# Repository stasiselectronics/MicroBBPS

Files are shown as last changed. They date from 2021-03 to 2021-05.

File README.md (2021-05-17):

# MicroBBPS
<h3>Breadboard Power Supply</h3>
<BR CLEAR=”left” />


A small, Micro USB connected power supply designed to fit onto the power rails of a solderless breadboard.

For each side, you can select between 3.3 & 5.0 Volt linear regulators, or the input voltage at the screw terminal. 

The integrated version adds 26 breadboard rows and 2 continuous power rails. So you can turn those prototypes into something more permanent with an easy microUSB power connector.

<h4><a href="https://github.com/stasiselectronics/MicroBBPS/tree/variant-integrated">Check out the integrated version's repository branch</a></h4>

## Documentation

If you would like to read more about how the design works and see some of the technical information, be sure to check out the documentation site that accompanies this project.

<h3><a href="https://stasiselectronics.github.io/MicroBBPS/">Read the Docs</a></h3>

This site is hosted on Github Pages, a great way to deploy your own static website using jekyll. It uses the wonderful theme [Minimal Mistakes](https://mmistakes.github.io/minimal-mistakes/about/) by Michael Rose.

[Learn more about github pages.](https://pages.github.com/)

## Development
This open source hardware project is developed using KiCAD and inkscape. It exists as a schematic and pcb design, with supporting files to create the necesarry output files for Printed Circuit Board fabrication.

[Learn more about KiCAD](https://kicad.org/about/kicad/)

## Status

Assemblies and Parts Kits are still available to purchase on Tindie, however current stock is starting to run low.

[Order Yours Today!](https://www.tindie.com/products/stasis/micro-breadboard-power-supply/)

The PCBA is currently at Revision A02. The tag for this release contians all the design files as they were when fabrication files were generated.

## Updates
If you would like to keep up to date with this project, be sure to check out my instagram

<h3><a href="https://www.instagram.com/stasis.electronics/">stasis.electronics</a></h3>

### A02 Fabrication

After incorporating the design changes from the first revision, the second revision came out great! 

There are still a few details to try and adjust for any future fabrication.
- Silkscreen adjustments for better image fidelity
- Still have some mechanical rocking on the solderless version when inserted into a breadboard

Some of the major changes between on A02 from A01 are
- Smaller board shape
- Changed LEDs to 1206 for better part availability and easier hand soldering
- Larger silkscreen features
- Integrated version

### A01 Fabrication
Here are some photos of the first board revision
<p align="center">
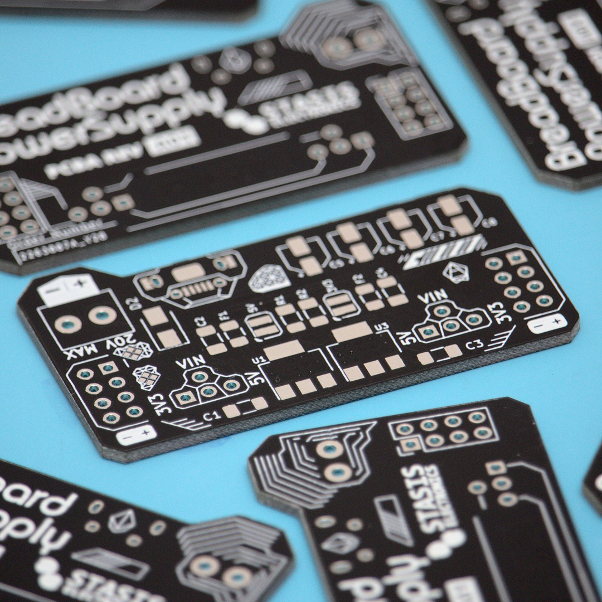
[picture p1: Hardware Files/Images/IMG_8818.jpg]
  
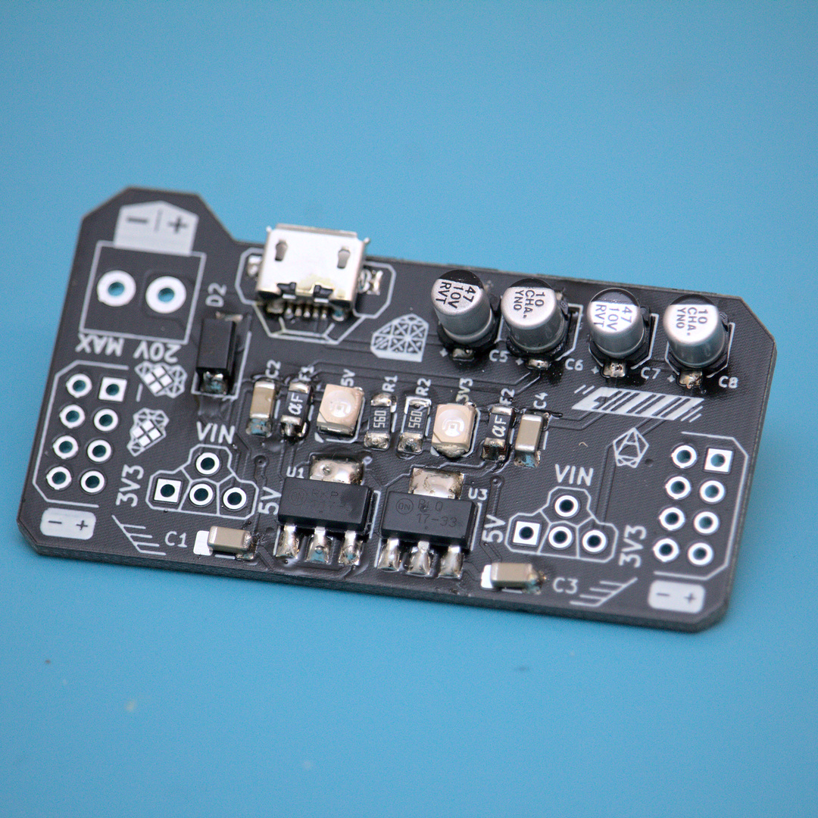
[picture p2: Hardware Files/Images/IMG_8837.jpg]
  
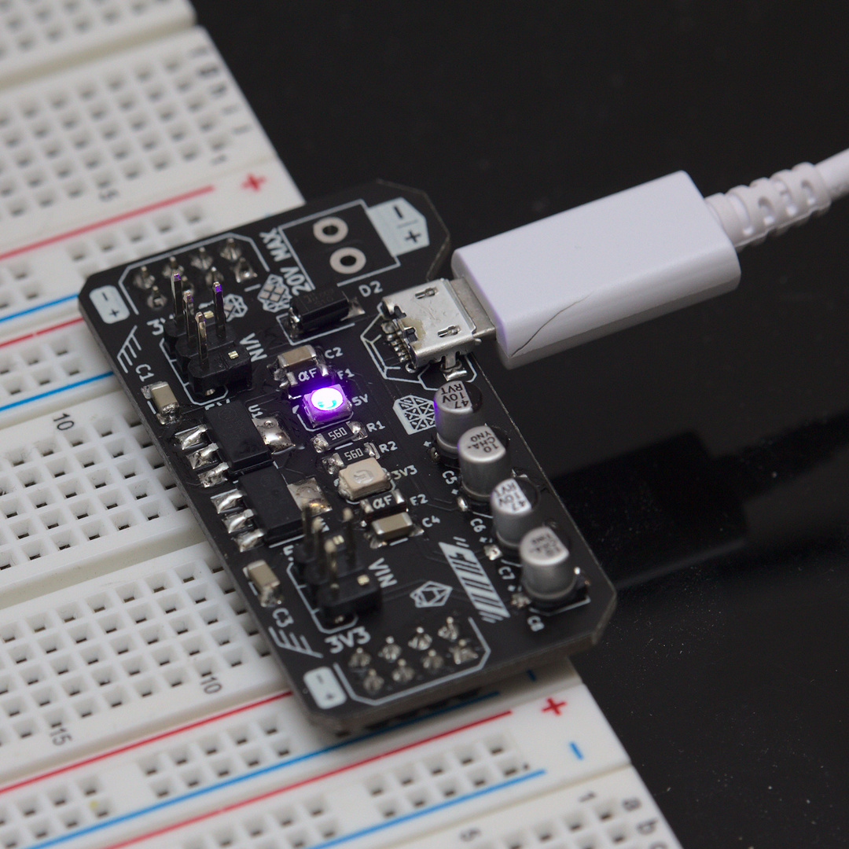
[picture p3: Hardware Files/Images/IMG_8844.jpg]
  
</p>

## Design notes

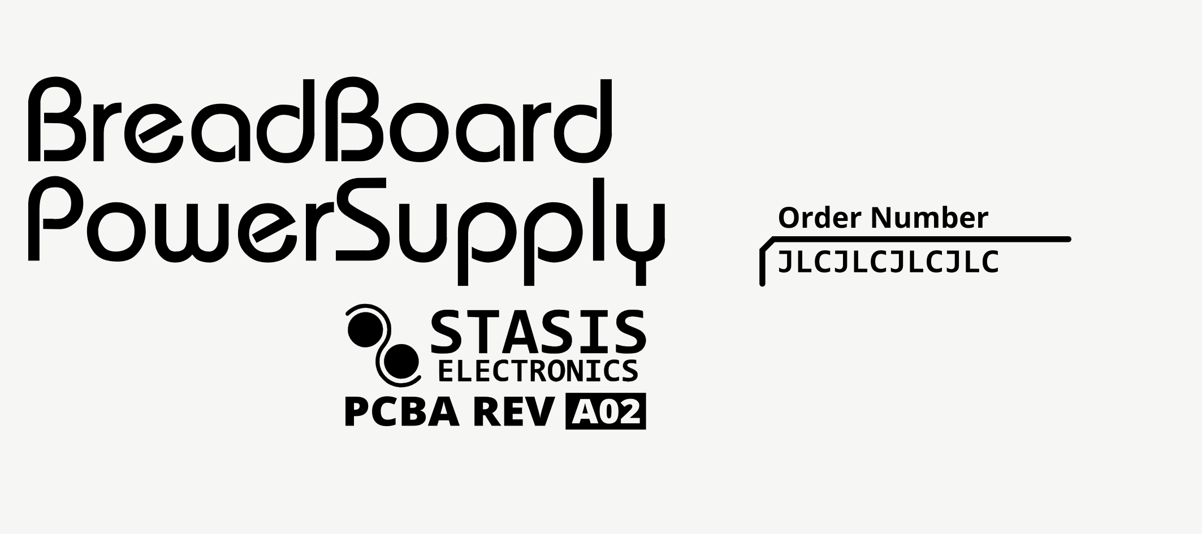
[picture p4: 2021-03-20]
Hardware Files/Input Files/artwork-bottom.png

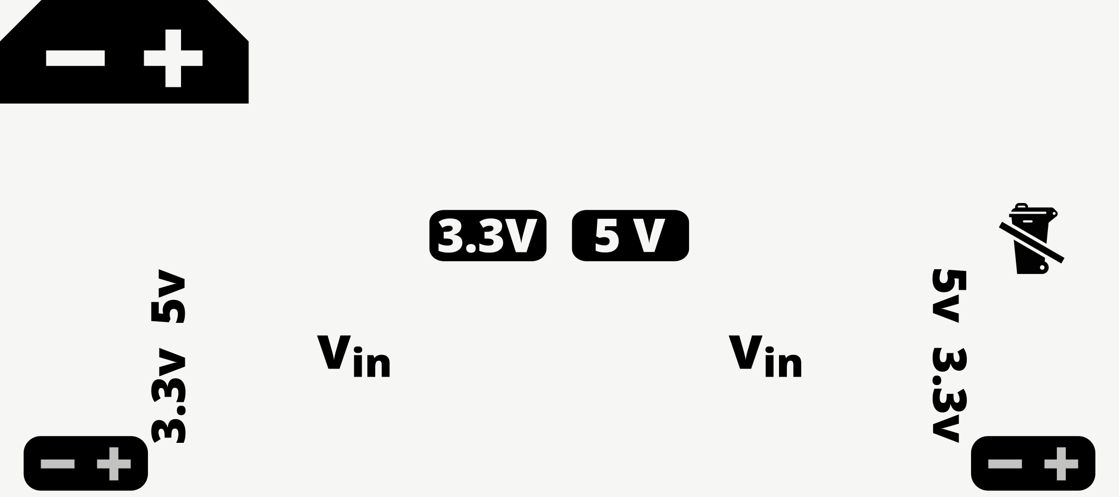
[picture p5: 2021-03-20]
Hardware Files/Input Files/artwork-top.png

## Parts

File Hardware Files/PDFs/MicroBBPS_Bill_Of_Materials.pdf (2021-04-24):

# Micro Breadboard Power Supply

Item Qty | Designator | Value | Part 1 MF | Part 1 MPN
1 | 2 | C5 C7 | 10µF 16V | Panasonic | EEEHA1C100R
2 | 4 | C1 C2 C3 C4 | 220nF 50V | YAGEO | CC1206KKX7R9BB224
3 | 2 | C6 C8 | 47µF 10V | ROQANG | RVT1A470M0405
4 | 1 | D2 | D | Diodes Incorporated | S1G-13-F
5 | 2 | D1 D3 | LED | EKINGLUX | E6C1206VGAC1UDA
6 | 4 | J3 J4 J8 J9 | 2x3 Header 2.54mm | XFCN | PZ254V-12-6P
7 | 1 | J5 | 1x2 Screw Terminal | Ningbo Kangnex Elec | WJ124-3.81-2P
8 | 1 | J2 | Micro USB Connector | Korean Hroparts Elec | U-F-M5DD-Y-L
9 | 2 | R1 R2 | 10k 0.25W | YAGEO | RC1206JR-0710KL
10 | 1 | U1 | 5.0V 1A linear Reg | ON Semiconductor | NCP1117ST50T3G
11 | 1 | U3 | 3.3V 1A Linear Reg | ON Semiconductor | NCP1117ST33T3G

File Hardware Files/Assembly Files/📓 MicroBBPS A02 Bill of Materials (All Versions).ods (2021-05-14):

Micro Breadboard Power Supply
Solderless
Item | Qty | Designator | Value | Part 1 MF | Part 1 MPN
1 | 2 | C5 C7 | 10µF 16V | Panasonic | EEEHA1C100R | ☐
2 | 4 | C1 C2 C3 C4 | 220nF 50V | YAGEO | CC1206KKX7R9BB224 | ☐
3 | 2 | C6 C8 | 47µF 10V | ROQANG | RVT1A470M0405 | ☐
4 | 1 | D2 | Gen Purp 400V 1A | Diodes Incorporated | S1G-13-F | ☐
5 | 2 | D1 D3 | Green LED | EKINGLUX | E6C1206VGAC1UDA | ☐
6 | 2 | J3 J4 | 2x3 Header 2.54mm | XFCN | PZ254V-12-6P | ☐
7 | 2 | J8 J9 | Modified Header | XFCN | PZ254V-12-6P | ☐
8 | 1 | J5 | 1x2 Screw Terminal | Ningbo Kangnex Elec | WJ124-3.81-2P | ☐
9 | 1 | J2 | Micro USB Connector | Korean Hroparts Elec | U-F-M5DD-Y-L | ☐
10 | 2 | R1 R2 | 10k 0.25W | YAGEO | RC1206JR-0710KL | ☐
11 | 1 | U1 | 5.0V 1A linear Reg | ON Semiconductor | NCP1117ST50T3G | ☐
12 | 1 | U3 | 3.3V 1A Linear Reg | ON Semiconductor | NCP1117ST33T3G | ☐
Micro Breadboard Power Supply
Integrated
Item | Qty | Designator | Value | Part 1 MF | Part 1 MPN
1 | 2 | C5 C7 | 10µF 16V | Panasonic | EEEHA1C100R | ☐
2 | 4 | C1 C2 C3 C4 | 220nF 50V | YAGEO | CC1206KKX7R9BB224 | ☐
3 | 2 | C6 C8 | 47µF 10V | ROQANG | RVT1A470M0405 | ☐
4 | 1 | D2 | Gen Purp 400V 1A | Diodes Incorporated | S1G-13-F | ☐
5 | 2 | D1 D3 | Green LED | EKINGLUX | E6C1206VGAC1UDA | ☐
6 | 2 | J8 J9 | Modified Header | XFCN | PZ254V-12-6P | ☐
7 | 1 | J5 | 1x2 Screw Terminal | Ningbo Kangnex Elec | WJ124-3.81-2P | ☐
8 | 1 | J2 | Micro USB Connector | Korean Hroparts Elec | U-F-M5DD-Y-L | ☐
9 | 2 | R1 R2 | 10k 0.25W | YAGEO | RC1206JR-0710KL | ☐
10 | 1 | U1 | 5.0V 1A linear Reg | ON Semiconductor | NCP1117ST50T3G | ☐
11 | 1 | U3 | 3.3V 1A Linear Reg | ON Semiconductor | NCP1117ST33T3G | ☐

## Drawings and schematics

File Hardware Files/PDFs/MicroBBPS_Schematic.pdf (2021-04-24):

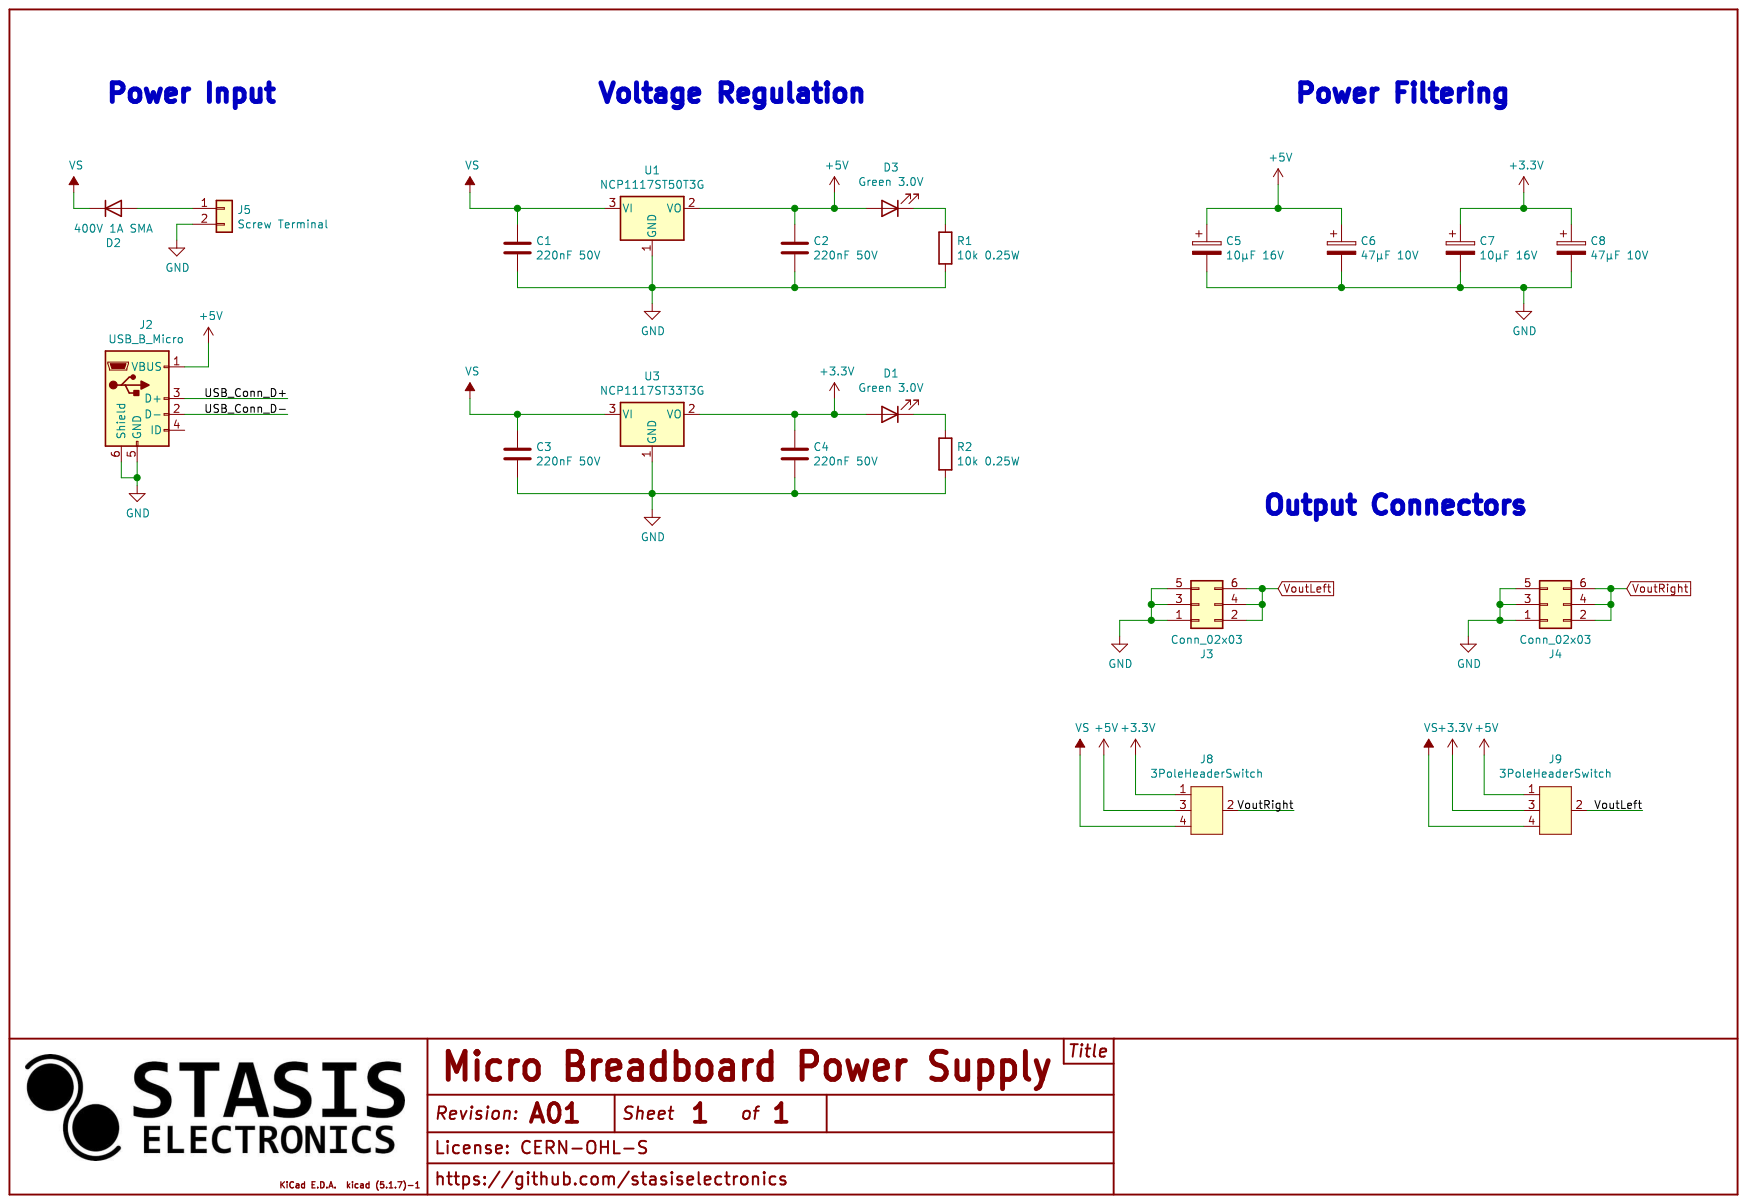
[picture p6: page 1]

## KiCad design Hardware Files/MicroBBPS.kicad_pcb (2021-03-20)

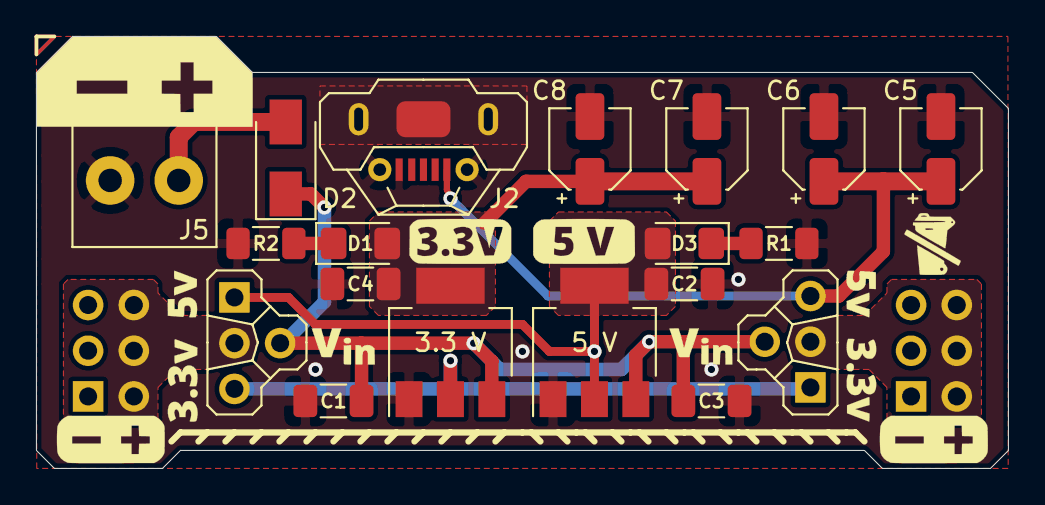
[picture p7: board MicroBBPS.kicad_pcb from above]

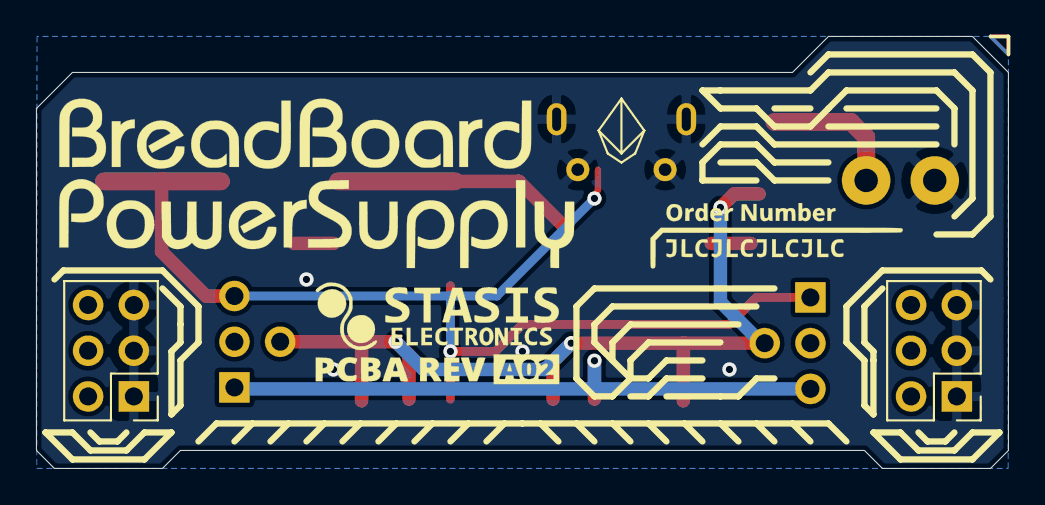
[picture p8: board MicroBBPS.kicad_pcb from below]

Board: 2 copper layers, 54.0 x 24.0 mm, 21 parts (2 on the bottom side), 9 nets.

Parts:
C1, C2, C3, C4: 220nF 50V; C_1206_3216Metric_Pad1.33x1.80mm_HandSolder
C5, C7: 10µF 16V; CP_Elec_4x5.4
C6, C8: 47µF 10V; CP_Elec_4x5.4
D1, D3: LED; D_1206_3216Metric_Pad1.42x1.75mm_HandSolder
D2: D; D_SMA
J2: USB_B_Micro; U-F-M5DD-Y-L
J3, J4: Conn_02x03; PinHeader_2x03_P2.54mm_Vertical
J5: Conn_01x02; WJ124-3.81-2P
J8, J9: 3PoleHeaderSwitch
R1: 56R 0.25W; R_1206_3216Metric_Pad1.30x1.75mm_HandSolder
R2: 0R; R_1206_3216Metric_Pad1.30x1.75mm_HandSolder
U1: NCP1117ST50T3G; SOT-223-3_TabPin2
U3: NCP1117ST33T3G; SOT-223-3_TabPin2

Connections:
+3V3: C4.1, C7.1, C8.1, D1.2, J8.1, J9.3, U3.2
+5V: C2.1, C5.1, C6.1, D3.2, J2.1, J8.3, J9.1, U1.2
/VoutLeft: J3.2, J3.4, J3.6, J9.2
/VoutRight: J4.2, J4.4, J4.6, J8.2
GND: C1.2, C2.2, C3.2, C4.2, C5.2, C6.2, C7.2, C8.2, J2.5, J2.6, J3.1, J3.3, J3.5, J4.1, J4.3, J4.5, J5.2, R1.2, R2.2, U1.1, U3.1
unnamed: D1.1, R2.1
unnamed: D2.2, J5.1
unnamed: D3.1, R1.1
VS: C1.1, C3.1, D2.1, J8.4, J9.4, U1.3, U3.3

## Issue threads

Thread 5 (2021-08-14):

Pin spacing

ilium007, 2021-08-14:
What is the exact distance between the outer pins? Thanks.

ChandlerMcCowan, 2021-08-14:
Hi!

The outer pins that interface with a breadboard are 1.9 inches apart.

This is the same on the integrated version as well.

Hope this helps and feel free to ask any follow up questions!

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

ilium007, 2021-08-14:
Thanks!

ilium007, 2021-08-14:
Sorry, one more question. How do you do those awesome reverse labels (3.3v / 5v)

ChandlerMcCowan, 2021-08-14:
No worries,

I use Inkscape to draw some of the artwork and then import it into KICAD as a footprint that just has silkscreen on it.

That makes it possible to use extra fonts, and draw more elaborate shapes.

Here's a video tutorial for [cutting text out of shapes in inkscape](https://www.youtube.com/watch?v=Men1K2oMq8g)

Keysight recently did a video about PCB artwork, I haven't watched it yet but [here it is](https://www.youtube.com/watch?v=0lomLQOFW8U)

ilium007, 2021-08-14:
So good! Thanks again.

ilium007, 2021-08-14:
I knew I had 'liked' something similar on Twitter a while back and just went back through my history and found it!

https://github.com/gregdavill/KiBuzzard

![Uploading C5B3B605-FD92-488B-B635-5E0F1B7A76FB.jpeg…]()

ilium007, 2021-08-14:
Works beautifully for simple text!

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

ChandlerMcCowan, 2021-08-14:
Nice! Looks good!

Closed 2021-08-14.

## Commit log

2020-11-11 Moved files into Hardware Files folder
    [MicroBBPS.kicad_pcb, MicroBBPS.sch]
2020-11-11 Add new page layout
    [MicroBBPS.sch]
2020-11-11 update page layout
    [MicroBBPS.kicad_pcb]
2021-01-07 Change board size to full breadboard length Move around components add 5v regulator add input terminal
    [MicroBBPS.kicad_pcb, MicroBBPS.sch]
2021-01-07 update layout add artwork update footprints
    [MicroBBPS.kicad_pcb, MicroBBPS.sch]
2021-01-07 Add footprint library add logos modify board shape add pours route some traces
    [MicroBBPS.kicad_pcb]
2021-01-08 Add new parts
    [MicroBBPS.sch]
2021-01-08 add 3D model
    [MicroBBPS.kicad_pcb]
2021-01-08 Change board shape Add more art finalize components finalize placement finalize routing
    [MicroBBPS.kicad_pcb, MicroBBPS.sch]
2021-01-09 Add part details
    [MicroBBPS.kicad_pcb, MicroBBPS.sch]
2021-01-09 Finalize components Finalize placement Finalize art Finalize BoM
    [MicroBBPS.kicad_pcb, MicroBBPS.sch, MicroBBPS_bom_A01.csv]
2021-01-09 Add Gerbers & NC Drill Files
    [MicroBBPS-B_Cu.gbr, MicroBBPS-B_Mask.gbr, MicroBBPS-B_SilkS.gbr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]
2021-01-09 change layer views
    [MicroBBPS.kicad_pcb]
2021-01-13 Finalize A01 Design
    [MicroBBPS-B_Cu.gbr, MicroBBPS-B_Mask.gbr, MicroBBPS-B_SilkS.gbr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]
2021-01-28 Add schematic PDF
2021-01-30 Update MPN and ordering code for Screw Terminal
    [MicroBBPS.sch]
2021-02-16 Add breadboard sections
    [MicroBBPS.kicad_pcb, MicroBBPS.sch]
2021-03-13 Clear Board Layout to redo it
    [MicroBBPS.kicad_pcb, MicroBBPS.sch]
2021-03-13 Place and route most components
    [MicroBBPS.kicad_pcb, MicroBBPS.sch]
2021-03-13 Finalize component placement and routing Board outline set to desired shape Breadboard rows in the right place Ready for artrwork
    [MicroBBPS.kicad_pcb, MicroBBPS.sch]
2021-03-15 Add power rail routes to both top and bottom layers
    [MicroBBPS.kicad_pcb]
2021-03-15 Clean up drawing layers and dimensions
    [MicroBBPS.kicad_pcb]
2021-03-20 Update board shape and add missing power rail routing
    [MicroBBPS.kicad_pcb]
2021-03-20 Update Board shape and fix some routing
    [MicroBBPS.kicad_pcb]
2021-03-20 Finalize routing and board shape
    [MicroBBPS.kicad_pcb, MicroBBPS.sch]
2021-03-20 Begin artwork
    [MicroBBPS.kicad_pcb]
2021-03-20 Finalize artwork, add missing files
    [MicroBBPS.kicad_pcb]
2021-03-20 Generate new gerbers
    [MicroBBPS-B_Cu.gbr, MicroBBPS-B_Mask.gbr, MicroBBPS-B_SilkS.gbr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]
2021-03-20 fab file plotting
    [MicroBBPS.kicad_pcb]
2021-03-20 Finalize artwork
    [MicroBBPS-B_Cu.gbr, MicroBBPS-B_Mask.gbr, MicroBBPS-B_SilkS.gbr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]
2021-03-20 update gerbers and artwork
    [MicroBBPS-B_Cu.gbr, MicroBBPS-B_Mask.gbr, MicroBBPS-B_SilkS.gbr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]
2021-03-21 Finalize component part info and update bom
    [MicroBBPS.sch, MicroBBPS_bom_A01.csv]
2021-03-21 Update part info for R2
    [MicroBBPS.sch]
2021-04-13 add new BOM
    [MicroBBPS_A02_BOM.ods, MicroBBPS_bom_A01.csv]
2021-04-13 add row spacing
    [MicroBBPS_A02_BOM.ods]
2021-04-24 update schematic
2021-04-24 update BOM
2021-04-24 update documentation
    [MicroBBPS.sch, MicroBBPS_A02_BOM.ods]
2021-05-14 Add BOM to cover both integrated and solderless versions
    [📓 MicroBBPS A02 Bill of Materials (All Versions).ods]
2021-08-29 add new bom for integrated version
    [MicroBBPS_A02_BOM_Integrated.ods]

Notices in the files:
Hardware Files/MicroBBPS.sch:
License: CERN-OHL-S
